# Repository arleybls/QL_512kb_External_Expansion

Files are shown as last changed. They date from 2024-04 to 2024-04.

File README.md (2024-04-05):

# SINCLAIR QL 512kB External Rom Expansion

(C) 2022 Alvaro Alea Fernandez, 2024 Revision By Arley (Jr) Silveira

License under: CERN Open Hardware Licence Version 2 - Strongly Reciprocal

https://ohwr.org/cern_ohl_s_v2.txt

This is based on the work of McLeod Ideafix, Jose Leandro, Zerover and tcat between others. 

This board will provide aditional 512kB of static RAM (fast-ram) to the sinclair QL.

It is incompatible with any aditional memory expansion on the QL.

Provide a expansion conector to allow conect aditional interfaces.

There area available 4 configuration trough solder jumpers in the PCB.
* 512kB - This is the standar 512kB expansion for any QL
* 256kB - This is for use as a second expansion, use the full QL space for a maximun of 898kB, be aware that this is incompatible with a lot of expansion card, so use with caution (Any expansion card that do not use jumper for configuration will be incompatible).
* 192kB - Similar to 256kB provide aditional space for expansion cards correctly configured.
* 128kB - Similar to 256kB provide aditional space for expansion cards correctly configured.

Be aware that the configuration of 128Kb can not be installed alone.
For be able to use 128kB, for a total of 768kB, is mandatory to have an aditional expansion card that put ROM in address E00000h, in other case the QL ROM will hang indicating RAM malfunction, because a weired overlap of the internal 128kB with this external 128kB.

https://www.instagram.com/p/CZWfWcUM5mx/

In the GAL folder there is the source code for winculp 

My image

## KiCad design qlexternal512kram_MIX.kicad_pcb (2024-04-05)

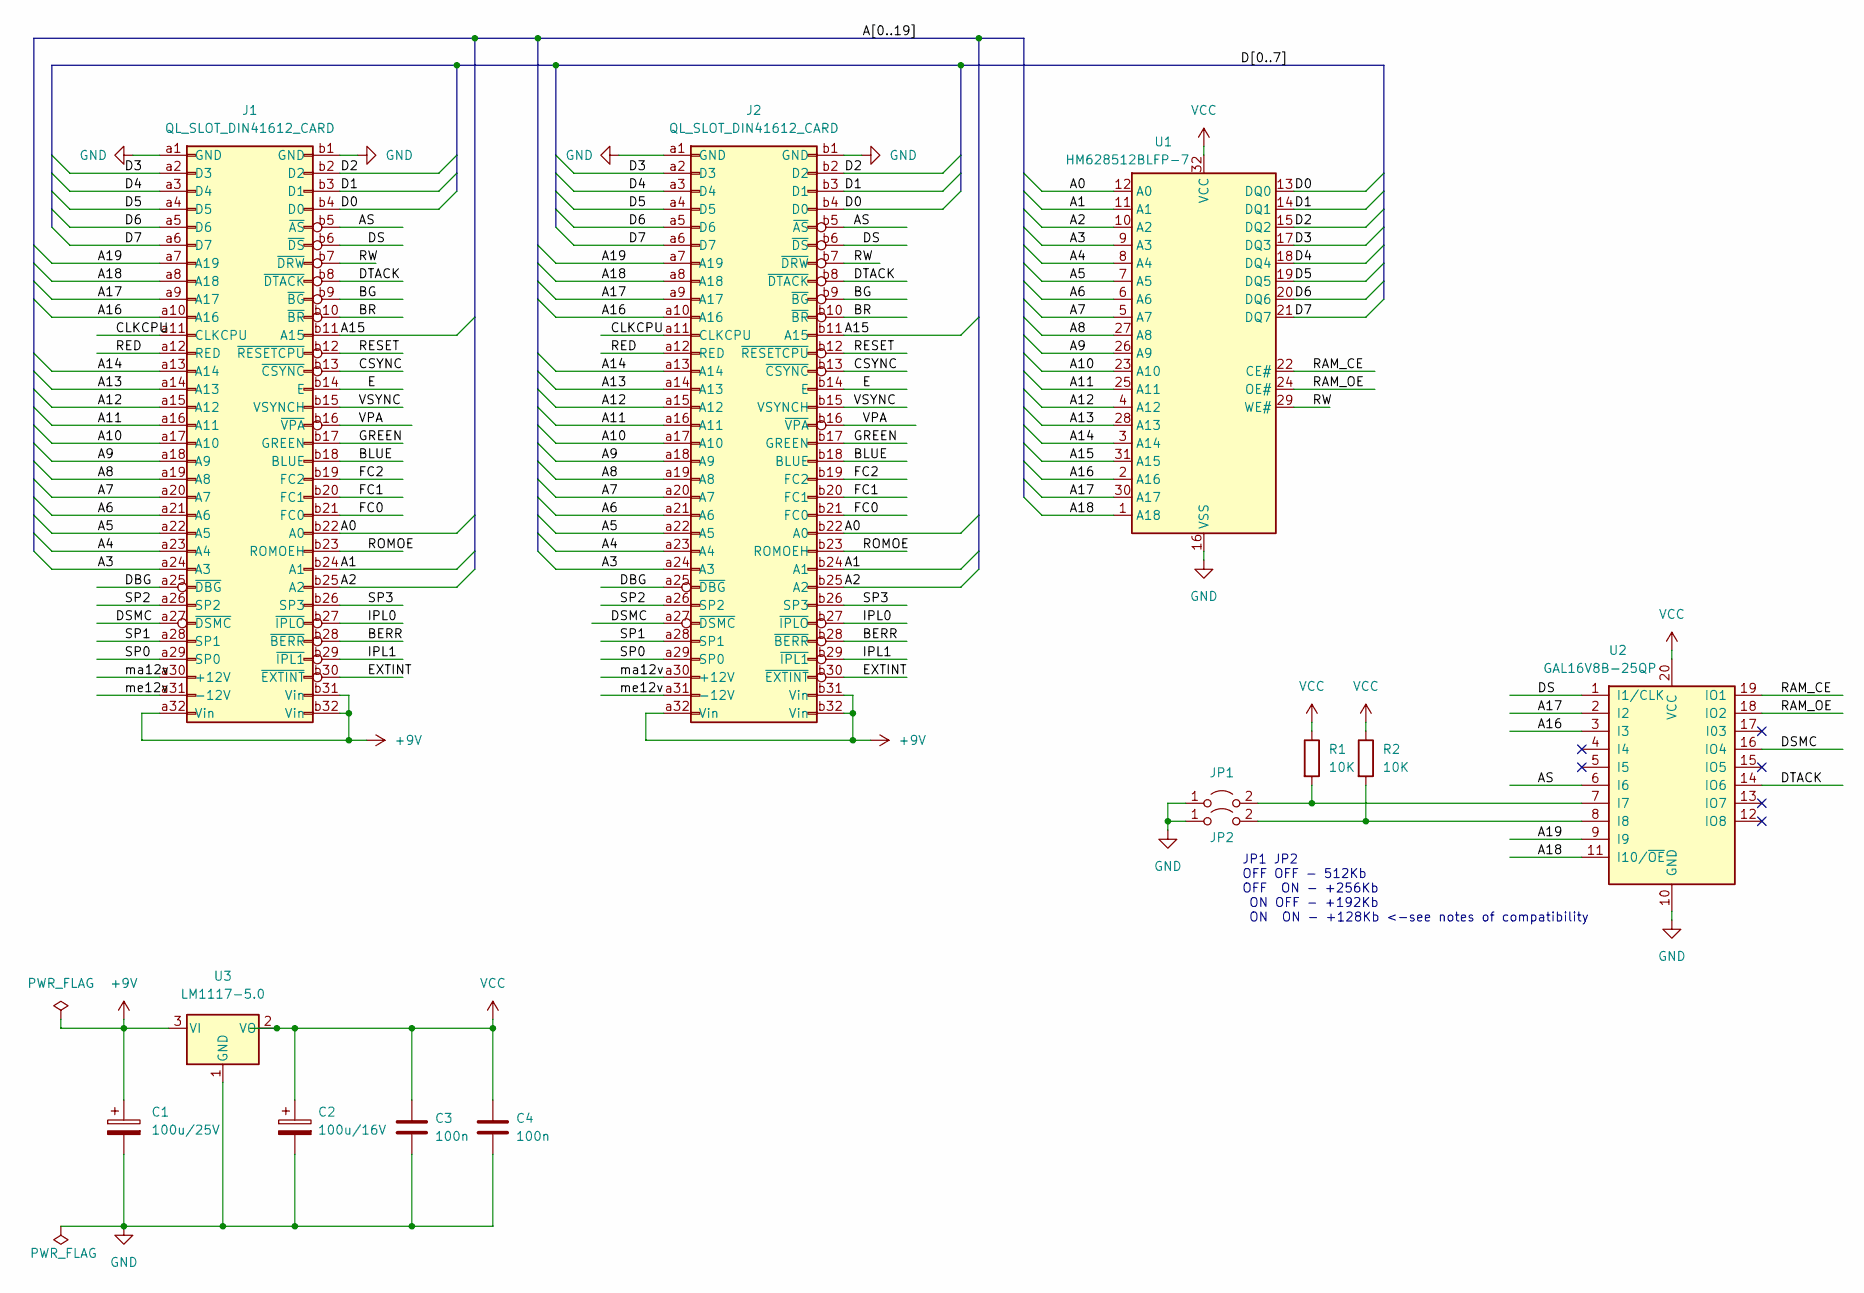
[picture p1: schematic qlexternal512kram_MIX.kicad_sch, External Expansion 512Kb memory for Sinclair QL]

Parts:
C1: 100u/25V; CP_Elec_6.3x5.4
C2: 100u/16V; CP_Elec_6.3x5.4
C3, C4: 100n; C_1206_3216Metric_Pad1.33x1.80mm_HandSolder
J1: QL_SLOT_DIN41612_CARD; DIN41612_B_2x32_Female_Horizontal_THT
J2: QL_SLOT_DIN41612_CARD; DIN41612_B_2x32_Male_Horizontal_THT
JP1, JP2: Jumper_2_Open; SolderJumper-2_P1.3mm_Open_Pad1.0x1.5mm
R1, R2: 10K; R_1206_3216Metric_Pad1.30x1.75mm_HandSolder
U1: HM628512BLFP-7; SSOP-32_11.305x20.495mm_P1.27mm
U2: GAL16V8B-25QP; DIP-20_W7.62mm_LongPads
U3: LM1117-5.0; SOT-223-3_TabPin2

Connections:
+9V: C1.1, J1.a32 (Vin), J1.b31 (Vin), J1.b32 (Vin), J2.a32 (Vin), J2.b31 (Vin), J2.b32 (Vin), U3.3 (VI)
/A0: J1.b22 (A0), J2.b22 (A0), U1.12 (A0)
/A1: J1.b24 (A1), J2.b24 (A1), U1.11 (A1)
/A2: J1.b25 (A2), J2.b25 (A2), U1.10 (A2)
/A3: J1.a24 (A3), J2.a24 (A3), U1.9 (A3)
/A4: J1.a23 (A4), J2.a23 (A4), U1.8 (A4)
/A5: J1.a22 (A5), J2.a22 (A5), U1.7 (A5)
/A6: J1.a21 (A6), J2.a21 (A6), U1.6 (A6)
/A7: J1.a20 (A7), J2.a20 (A7), U1.5 (A7)
/A8: J1.a19 (A8), J2.a19 (A8), U1.27 (A8)
/A9: J1.a18 (A9), J2.a18 (A9), U1.26 (A9)
/A10: J1.a17 (A10), J2.a17 (A10), U1.23 (A10)
/A11: J1.a16 (A11), J2.a16 (A11), U1.25 (A11)
/A12: J1.a15 (A12), J2.a15 (A12), U1.4 (A12)
/A13: J1.a14 (A13), J2.a14 (A13), U1.28 (A13)
/A14: J1.a13 (A14), J2.a13 (A14), U1.3 (A14)
/A15: J1.b11 (A15), J2.b11 (A15), U1.31 (A15)
/A16: J1.a10 (A16), J2.a10 (A16), U1.2 (A16), U2.3 (I3)
/A17: J1.a9 (A17), J2.a9 (A17), U1.30 (A17), U2.2 (I2)
/A18: J1.a8 (A18), J2.a8 (A18), U1.1 (A18), U2.11 (I10/~OE)
/A19: J1.a7 (A19), J2.a7 (A19), U2.9 (I9)
/AS: J1.b5 (~AS), J2.b5 (~AS), U2.6 (I6)
/BERR: J1.b28 (~BERR), J2.b28 (~BERR)
/BG: J1.b9 (~BG), J2.b9 (~BG)
/BLUE: J1.b18 (BLUE), J2.b18 (BLUE)
/BR: J1.b10 (~BR), J2.b10 (~BR)
/CLKCPU: J1.a11 (CLKCPU), J2.a11 (CLKCPU)
/CSYNC: J1.b13 (~CSYNC), J2.b13 (~CSYNC)
/D0: J1.b4 (D0), J2.b4 (D0), U1.13 (DQ0)
/D1: J1.b3 (D1), J2.b3 (D1), U1.14 (DQ1)
/D2: J1.b2 (D2), J2.b2 (D2), U1.15 (DQ2)
/D3: J1.a2 (D3), J2.a2 (D3), U1.17 (DQ3)
/D4: J1.a3 (D4), J2.a3 (D4), U1.18 (DQ4)
/D5: J1.a4 (D5), J2.a4 (D5), U1.19 (DQ5)
/D6: J1.a5 (D6), J2.a5 (D6), U1.20 (DQ6)
/D7: J1.a6 (D7), J2.a6 (D7), U1.21 (DQ7)
/DBG: J1.a25 (~DBG), J2.a25 (~DBG)
/DS: J1.b6 (~DS), J2.b6 (~DS), U2.1 (I1/CLK)
/DSMC: J1.a27 (~DSMC), J2.a27 (~DSMC), U2.16 (IO4)
/DTACK: J1.b8 (~DTACK), J2.b8 (~DTACK), U2.14 (IO6)
/E: J1.b14 (E), J2.b14 (E)
/EXTINT: J1.b30 (~EXTINT), J2.b30 (~EXTINT)
/FC0: J1.b21 (FC0), J2.b21 (FC0)
/FC1: J1.b20 (FC1), J2.b20 (FC1)
/FC2: J1.b19 (FC2), J2.b19 (FC2)
/GREEN: J1.b17 (GREEN), J2.b17 (GREEN)
/IPL0: J1.b27 (~IPLO), J2.b27 (~IPLO)
/IPL1: J1.b29 (~IPL1), J2.b29 (~IPL1)
/RAM_CE: U1.22 (CE#), U2.19 (IO1)
/RAM_OE: U1.24 (OE#), U2.18 (IO2)
/RED: J1.a12 (RED), J2.a12 (RED)
/RESET: J1.b12 (~RESETCPU), J2.b12 (~RESETCPU)
/ROMOE: J1.b23 (ROMOEH), J2.b23 (ROMOEH)
/RW: J1.b7 (~DRW), J2.b7 (~DRW), U1.29 (WE#)
/SP0: J1.a29 (SP0), J2.a29 (SP0)
/SP1: J1.a28 (SP1), J2.a28 (SP1)
/SP2: J1.a26 (SP2), J2.a26 (SP2)
/SP3: J1.b26 (SP3), J2.b26 (SP3)
/VPA: J1.b16 (~VPA), J2.b16 (~VPA)
/VSYNC: J1.b15 (VSYNCH), J2.b15 (VSYNCH)
/ma12v: J1.a30 (+12V), J2.a30 (+12V)
/me12v: J1.a31 (-12V), J2.a31 (-12V)
GND: C1.2, C2.2, C3.2, C4.2, J1.a1 (GND), J1.b1 (GND), J2.a1 (GND), J2.b1 (GND), JP1.1 (A), JP2.1 (A), U1.16 (VSS), U2.10 (GND), U3.1 (GND)
unnamed: JP1.2 (B), R1.2, U2.7 (I7)
unnamed: JP2.2 (B), R2.2, U2.8 (I8)
VCC: C2.1, C3.1, C4.1, R1.1, R2.1, U1.32 (VCC), U2.20 (VCC), U3.2 (VO)

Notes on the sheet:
JP1 JP2 OFF OFF - 512Kb OFF ON - +256Kb ON OFF - +192Kb ON ON - +128Kb <-see notes of compatibility

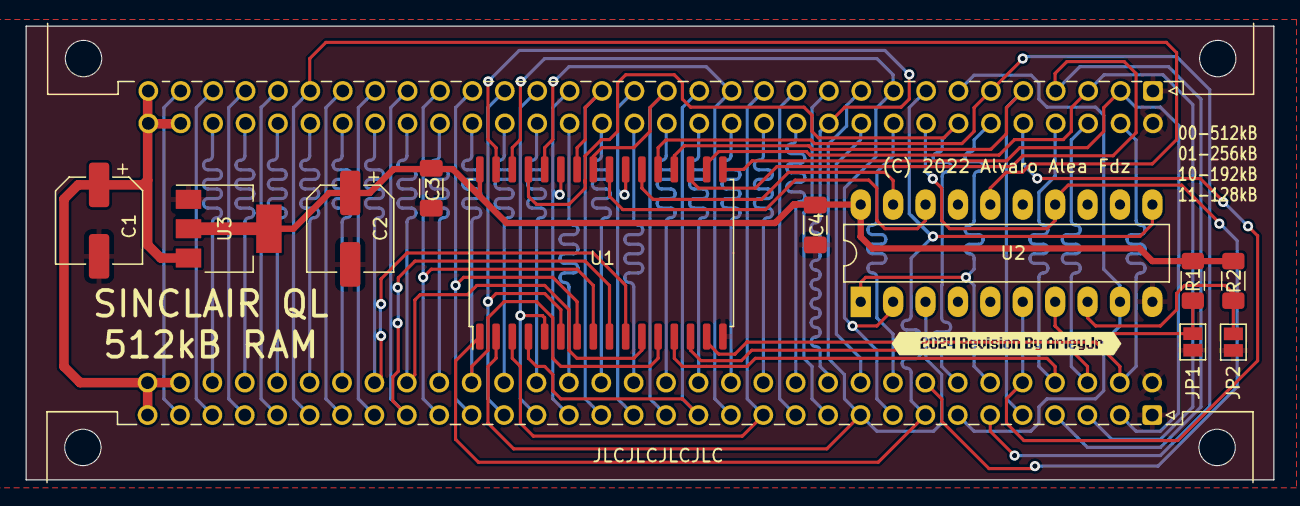
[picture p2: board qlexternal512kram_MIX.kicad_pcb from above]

Board: 2 copper layers, 97.8 x 35.6 mm, 14 parts (0 on the bottom side), 66 nets.

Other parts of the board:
kibuzzard-660FAAE3: G***; kibuzzard-660FAAE3

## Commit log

2024-04-05 Revision 0.01
    [qlexternal512kram_MIX.kicad_pcb, qlexternal512kram_MIX.kicad_sch]
2024-04-05 Revision Information and Gerbers
    [qlexternal512kram_MIX-B_Cu.gbr, qlexternal512kram_MIX-B_Mask.gbr, qlexternal512kram_MIX-B_Paste.gbr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]
2024-04-05 Small adjustment to the last commit
    [qlexternal512kram_MIX-B_Cu.gbr, qlexternal512kram_MIX-B_Mask.gbr, qlexternal512kram_MIX-B_Paste.gbr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]

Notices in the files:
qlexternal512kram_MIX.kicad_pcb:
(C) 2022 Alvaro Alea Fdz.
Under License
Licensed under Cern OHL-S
